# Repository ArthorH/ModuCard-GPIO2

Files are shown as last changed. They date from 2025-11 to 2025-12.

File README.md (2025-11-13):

# ModuCard Base Module STM32H563VBT6

This repository provides a template design for creating modules in the ModuCard system. Each module is designed to seamlessly interface with the [ModuCard backplane](https://github.com/KoNarRobotics/ModuCard-backplane), enabling a modular and expandable robotics platform.
obraz

## Used tools:
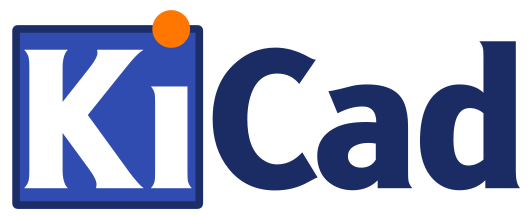
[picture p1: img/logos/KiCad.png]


## Features:

### Power section
- **Input voltage:** 12V from the backplane.  
- **Output voltage:** 3.3V @ 0.5A.

### ST-LINK
- Built-in **ST-LINK** connected to the backplane via USB interface.  
- Enables programming and debugging of the onboard MCU.

### CAN interface
- Two independent CAN buses: **CAN1** and **CAN2**.  
- Both connect with the backplane to facilitate communication between the onboard MCU and other modules in the system.

# How to Create a new module from this template
1. **Create a new repository**
2. **Copy files from this repository** to your new repository.  
3. **Rename the files:**
   - `base-module.kicad_pcb` → `<your-board-name>.kicad_pcb`
   - `base-module.kicad_sch` → `<your-board-name>.kicad_sch`
   - `base-module.kicad_pro` → `<your-board-name>.kicad_pro`
4. **Open the project** in KiCad.  
5. **Update page settings** in the schematic and PCB:
   - Change the **Title** to `ModuCard <your project name>`.  
   - Edit **Comment 2** to include your name in the `<author>` field.
6. Enjoy implementing your project!

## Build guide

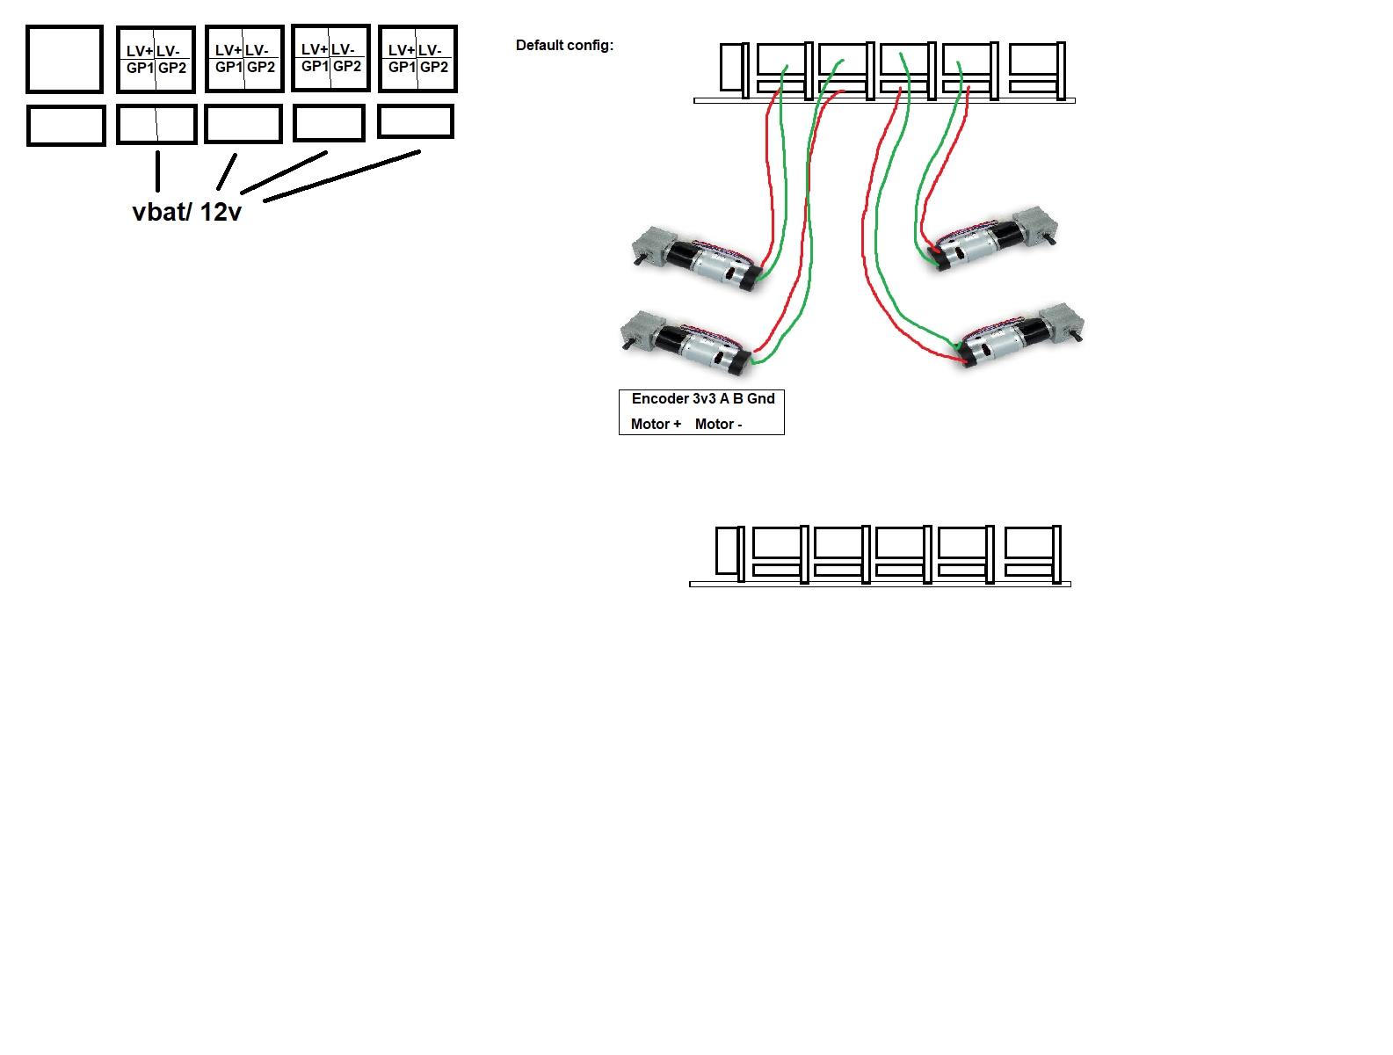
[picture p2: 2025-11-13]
doc/Usage.png

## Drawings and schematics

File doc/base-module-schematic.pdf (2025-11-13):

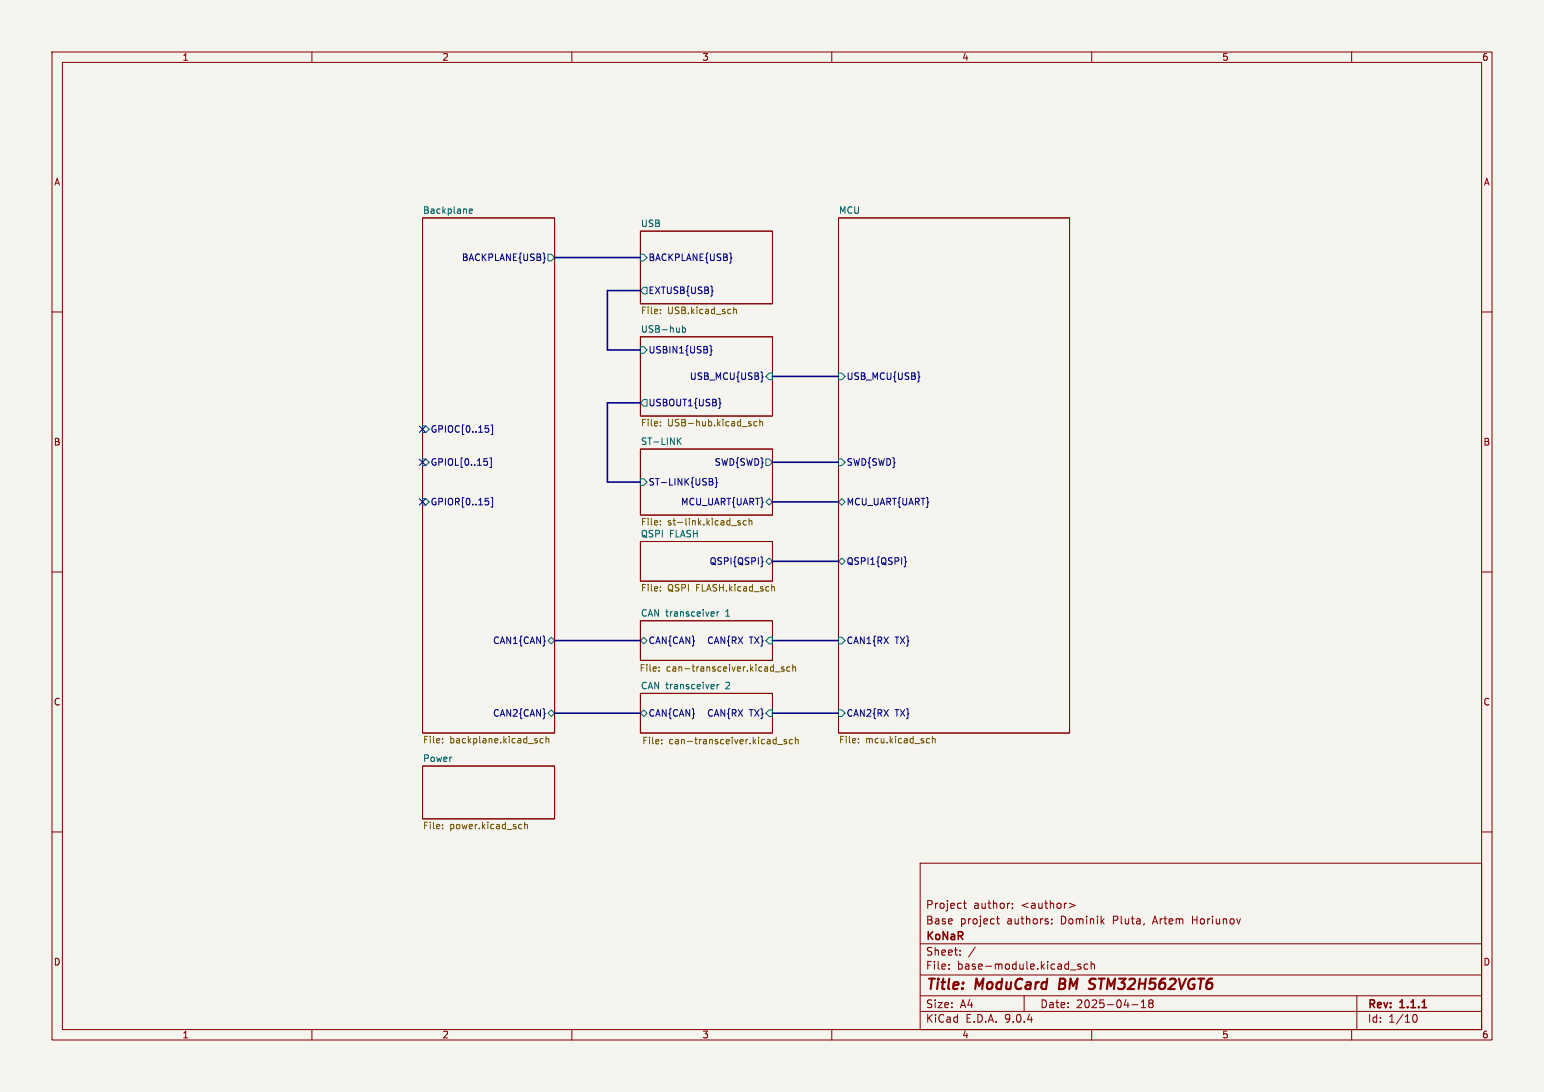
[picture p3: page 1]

Backplane File: backplane.kicad_sch
File: USB.kicad_sch ST-LINK{USB}
USB_MCU{USB} USB-hub File: USB-hub.kicad_sch

File: QSPI FLASH.kicad_sch USBIN1{USB}

File: st-link.kicad_sch QSPI{QSPI} QSPI FLASH

File: base-module.kicad_sch Sheet: / KoNaR

Id: 1/10 Title: ModuCard BM STM32H562VGT6

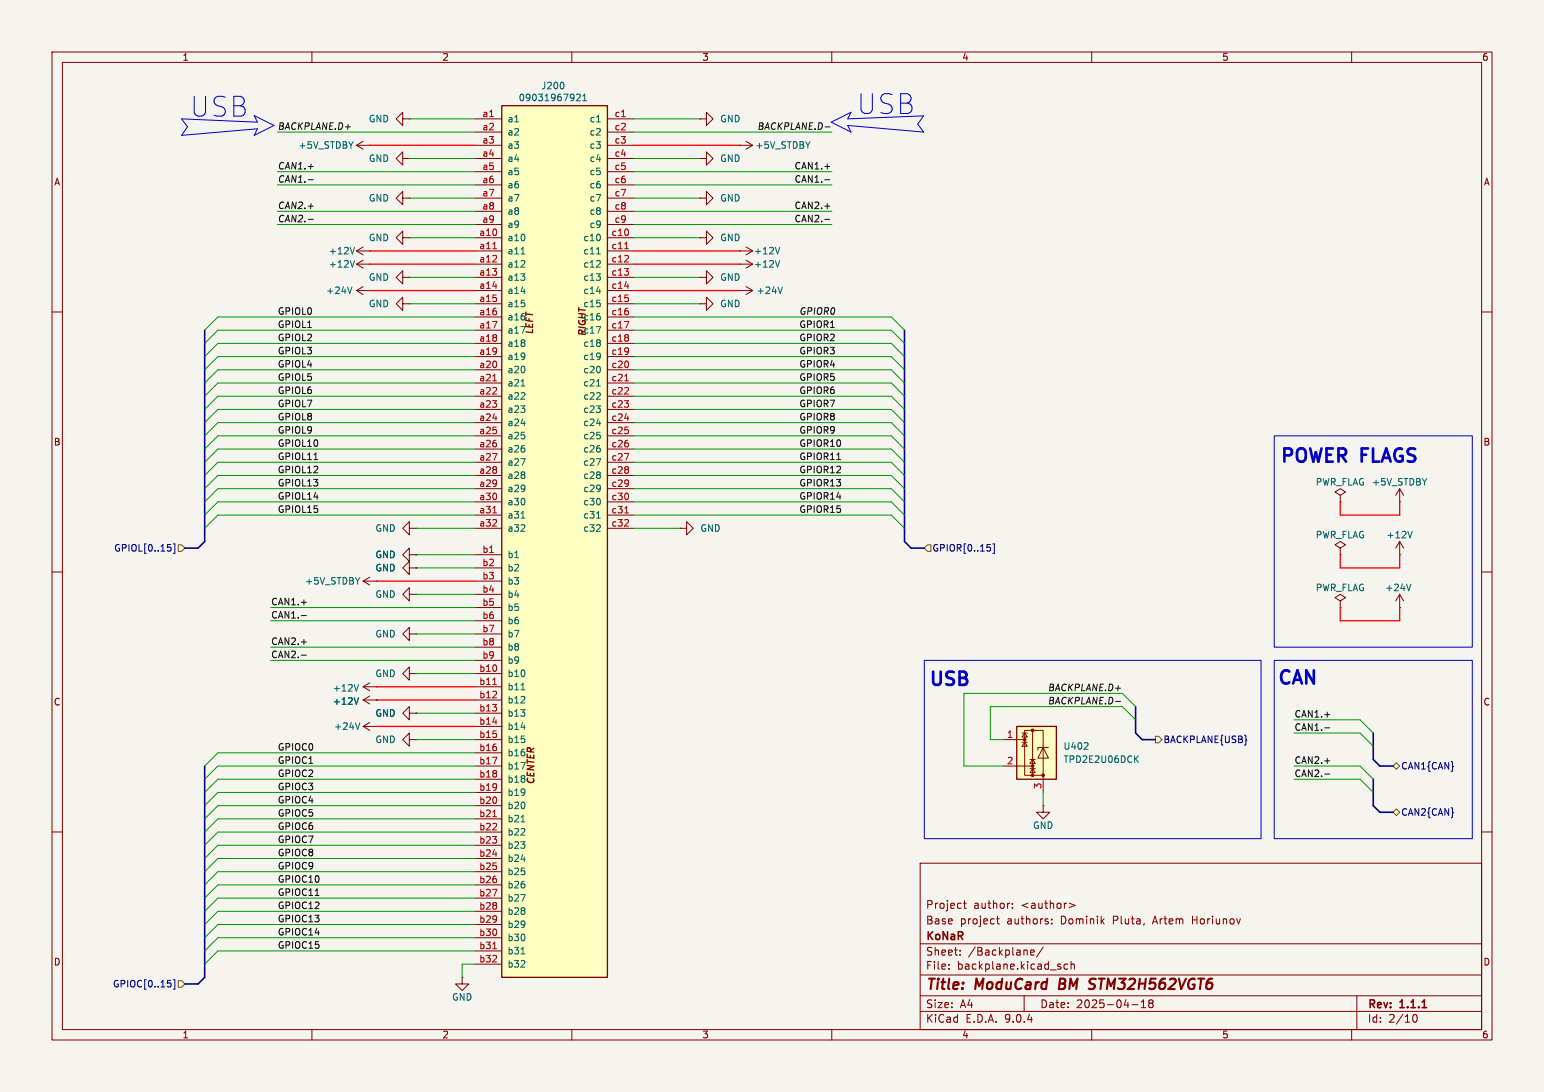
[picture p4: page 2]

File: backplane.kicad_sch Sheet: /Backplane/ KoNaR

Id: 2/10 Title: ModuCard BM STM32H562VGT6

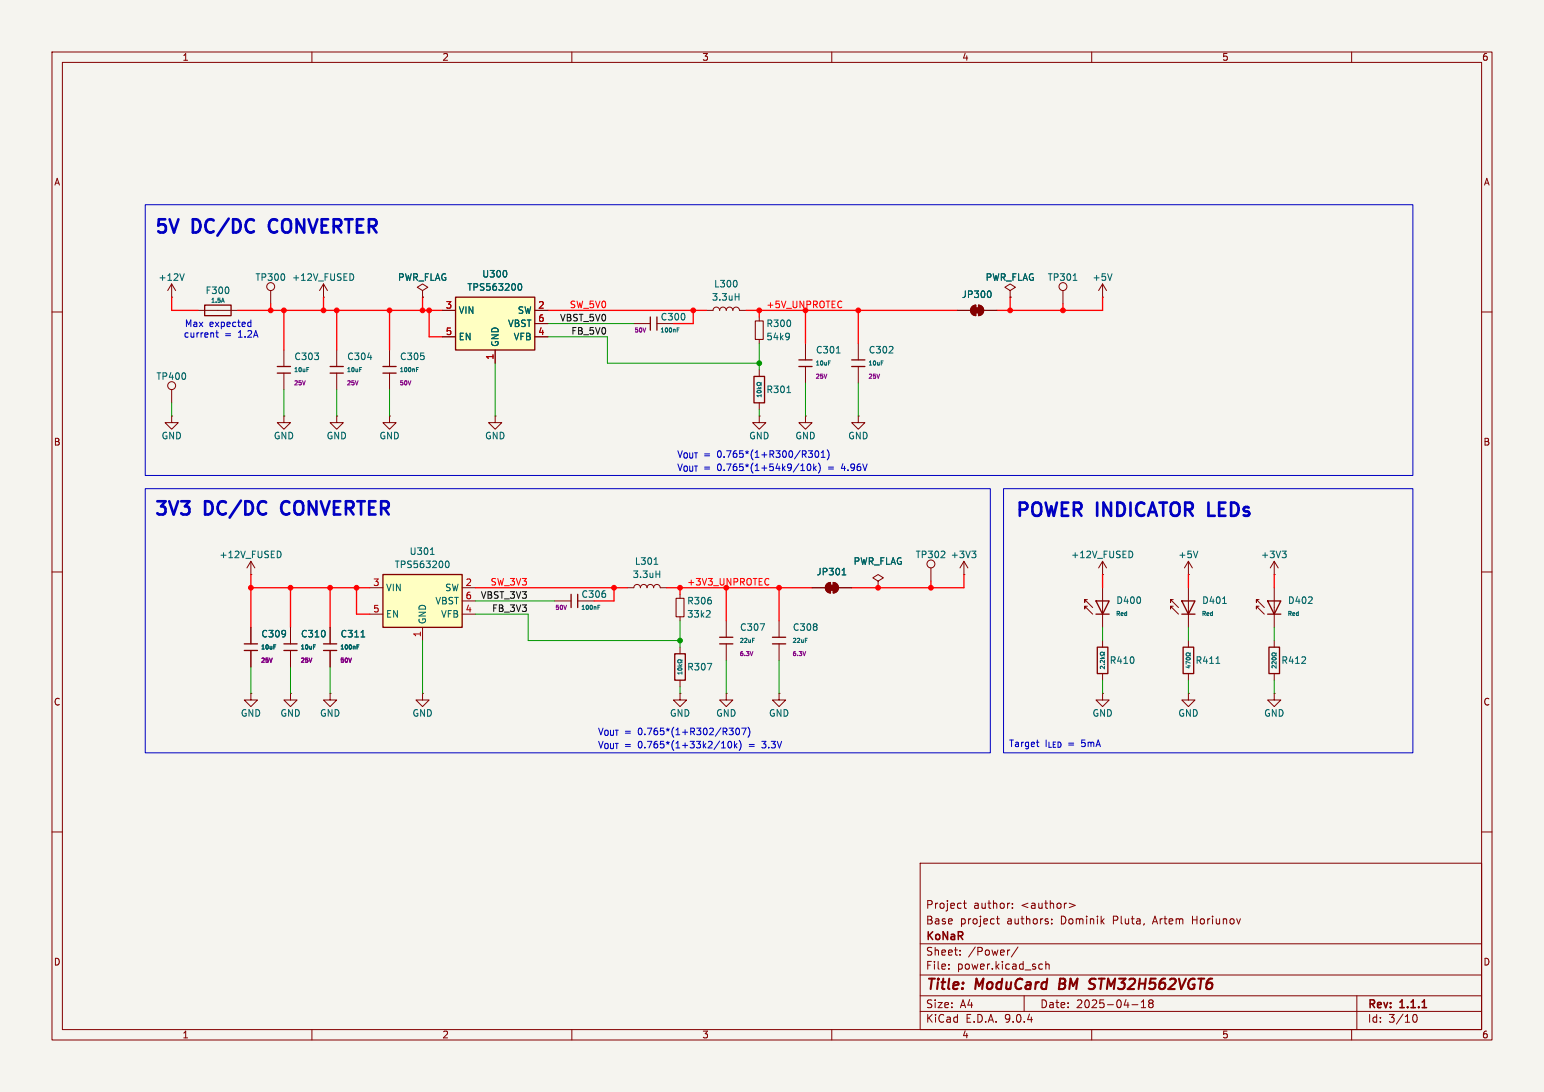
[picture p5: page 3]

1 SW 2 VBST 6 VFB 4 U300 TPS563200 GND GND

current = 1.2A 3V3 DC/DC CONVERTER

R412 þÿ220© +5VR411 þÿ470© R301 þÿ10k© GND

File: power.kicad_sch Sheet: /Power/ KoNaR

Id: 3/10 Title: ModuCard BM STM32H562VGT6

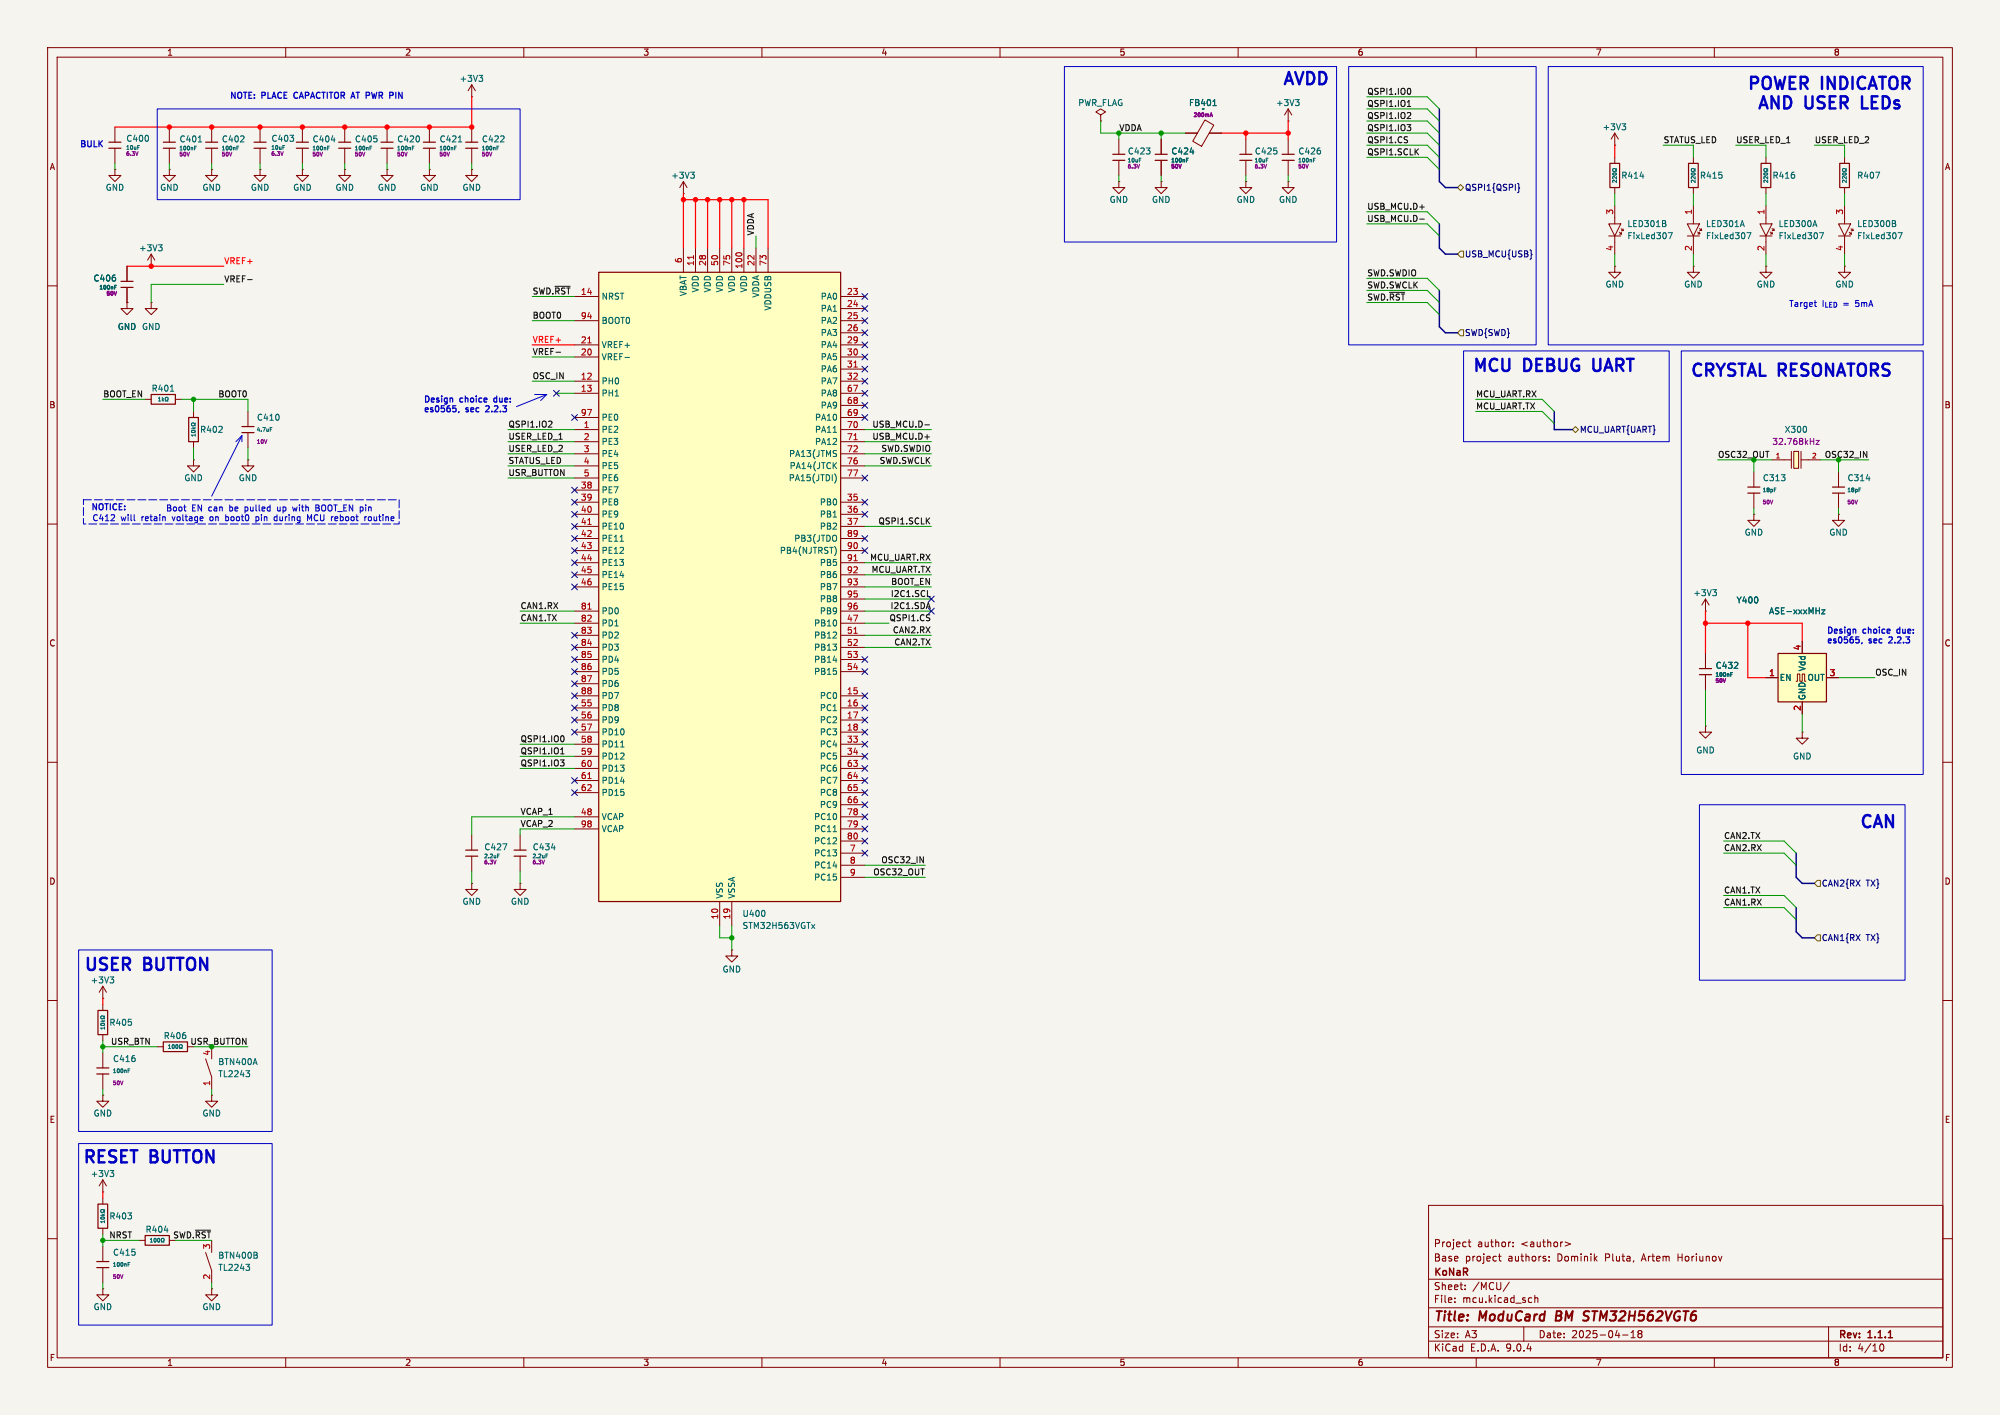
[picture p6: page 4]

6 VDD 11 VDD 28 VDD 50 VSS 10 VDD 75 VSSA 19 VDD 100 VDDA 22 VDDUSB 73 PA0 23 PA1 24 PA2 25 PA3 26 PA4 29 PA5 30 PA6 31 PA7 32 PA8 67 PA9 68 PA10 69 PA11 70 PA12 71 PA13(JTMS 72 PA14(JTCK 76 PA15(JTDI) 77 PB0 35 PB1 36 PB2 37 PB3(JTDO 89 PB4(NJTRST) 90 PB5 91 PB6 92 PB7 93 PB8 95 PB9 96 PB10 47 PB12 51 PB13 52 PB14 53 PB15 54 PC0 15 PC1 16 PC2 17 PC3 18 PC4 33 PC5 34 PC6 63 PC7 64 PC8 65 PC9 66 PC10 78 PC11 79 PC12 80 PC13 7 PC14 8 PC15 9 U400 STM32H563VGTx

File: mcu.kicad_sch Sheet: /MCU/ KoNaR

Id: 4/10 Title: ModuCard BM STM32H562VGT6

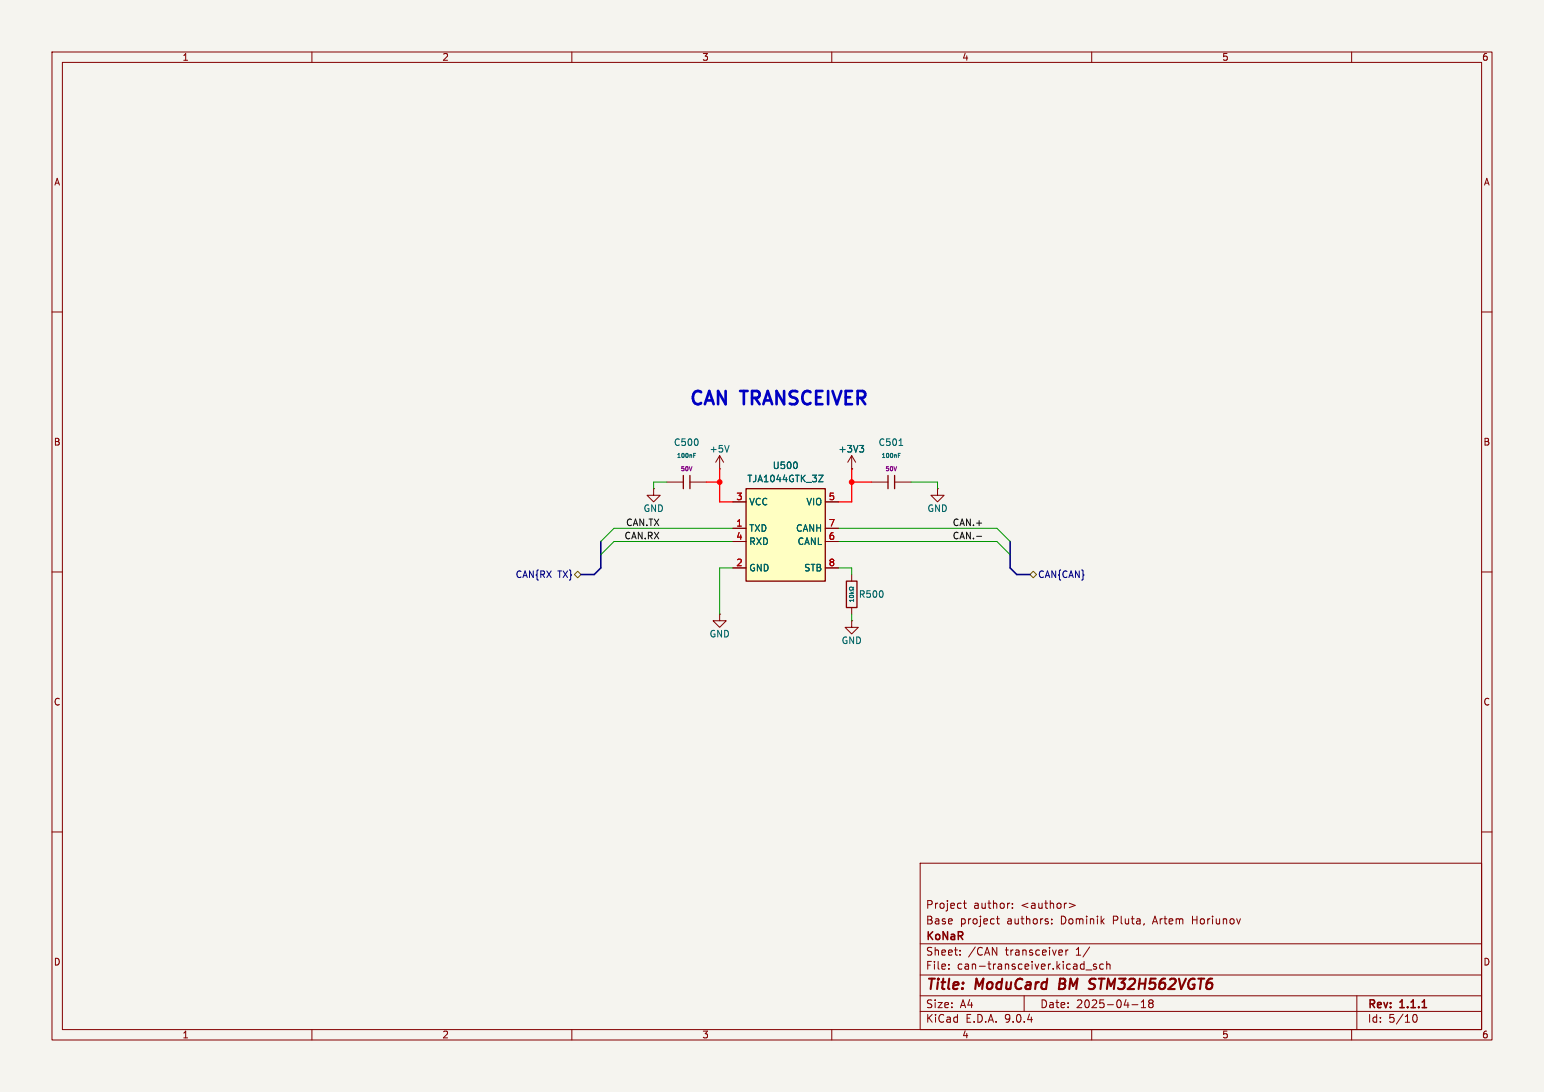
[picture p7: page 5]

Id: 5/10 Title: ModuCard BM STM32H562VGT6

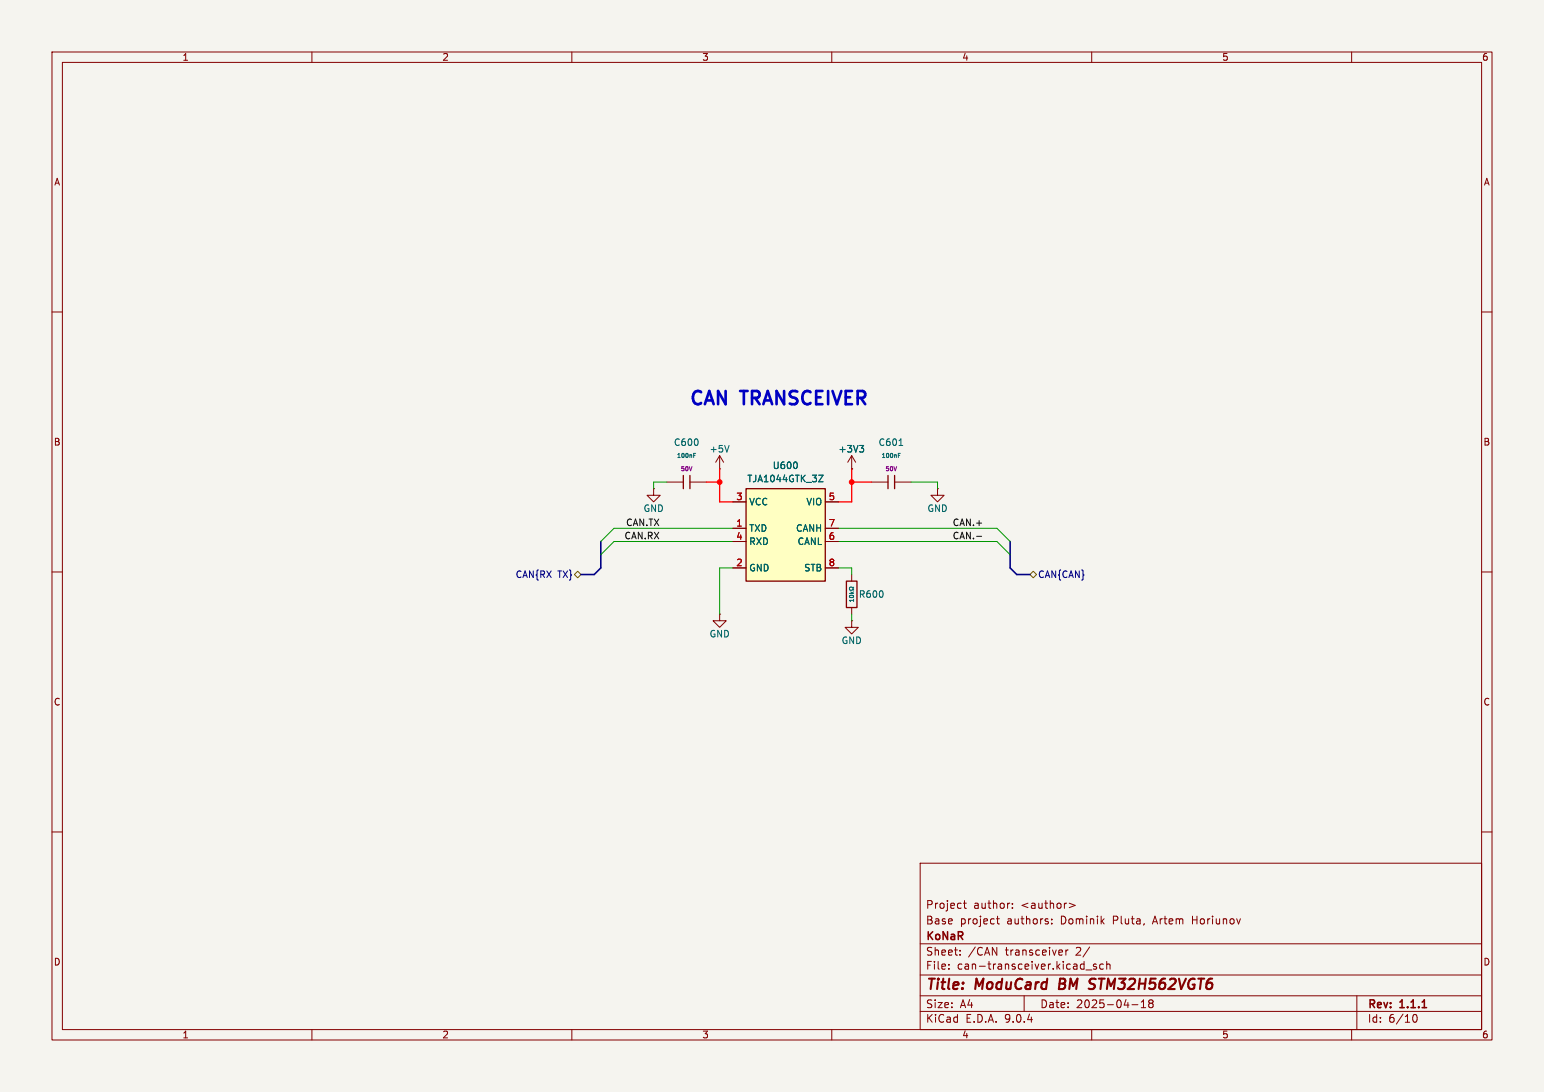
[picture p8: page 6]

Id: 6/10 Title: ModuCard BM STM32H562VGT6

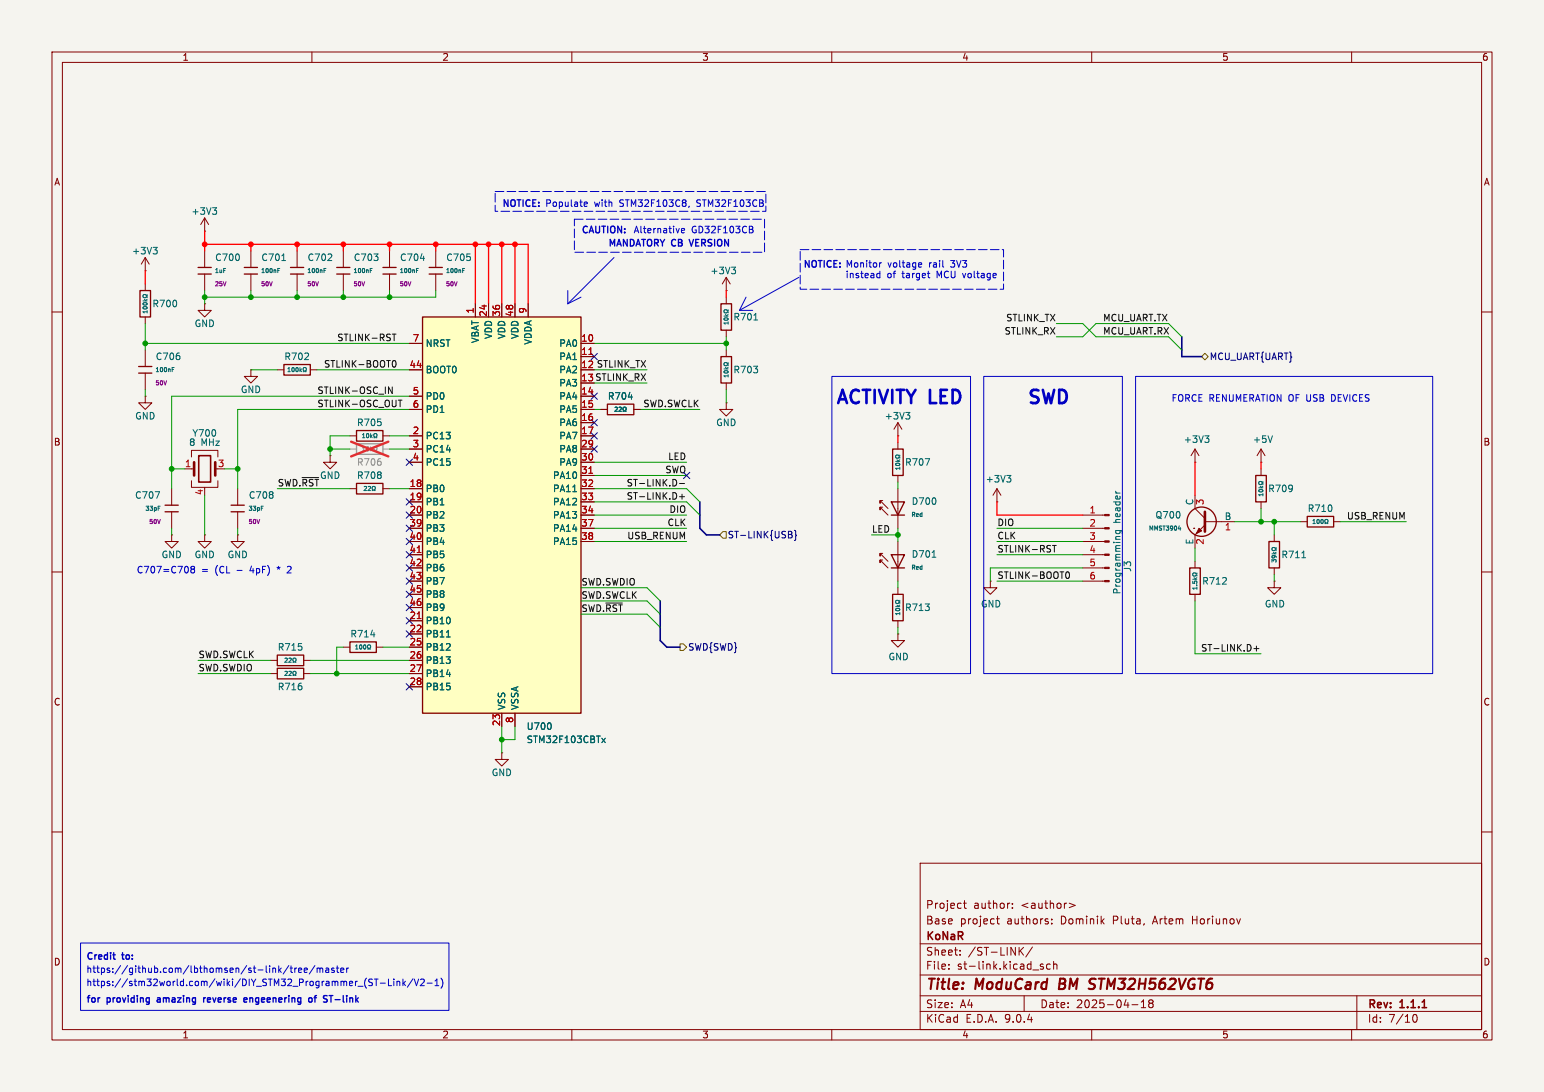
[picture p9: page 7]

instead of target MCU voltage

1 VDD 24 VDD 36 VSS 23 VDD 48 VSSA

ST-LINK.D+ ST-LINK.D- SWD.SWCLK

SWD.SWDIO
SWD.~{RST} SWD.SWCLK

File: st-link.kicad_sch Sheet: /ST-LINK/ KoNaR

https://stm32world.com/wiki/DIY_STM32_Programmer_(ST-Link/V2-1)
for providing amazing reverse engeenering of ST-link

Id: 7/10 Title: ModuCard BM STM32H562VGT6

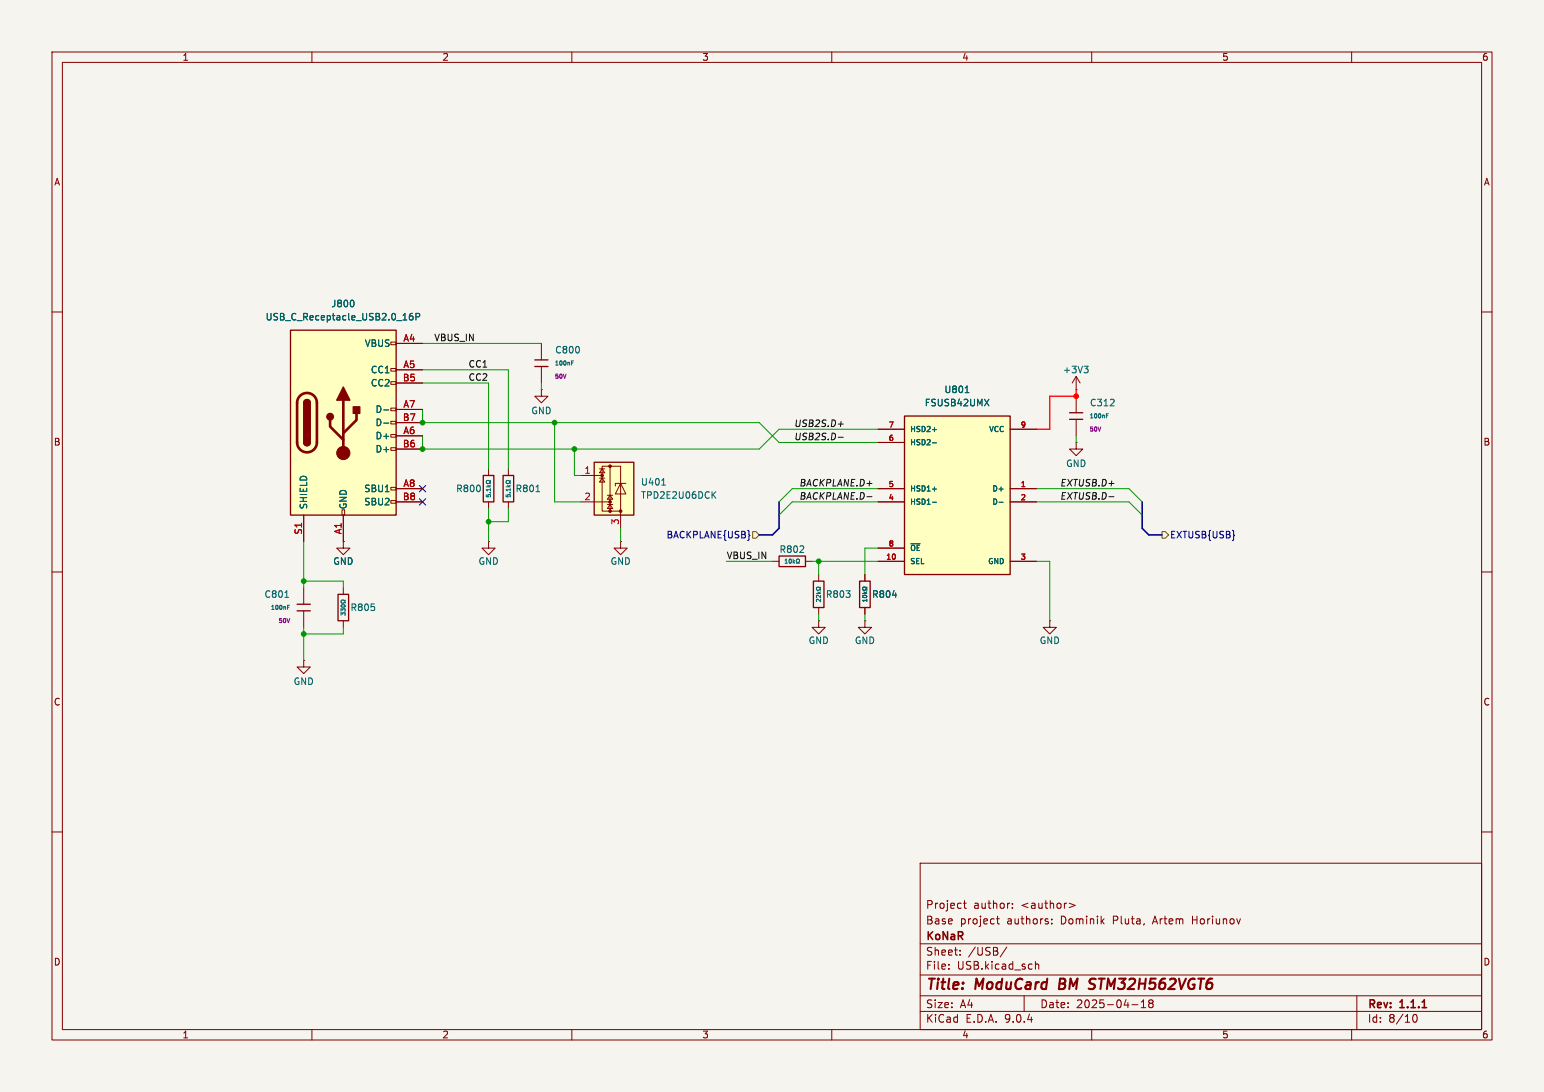
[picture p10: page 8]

File: USB.kicad_sch Sheet: /USB/ KoNaR

Id: 8/10 Title: ModuCard BM STM32H562VGT6

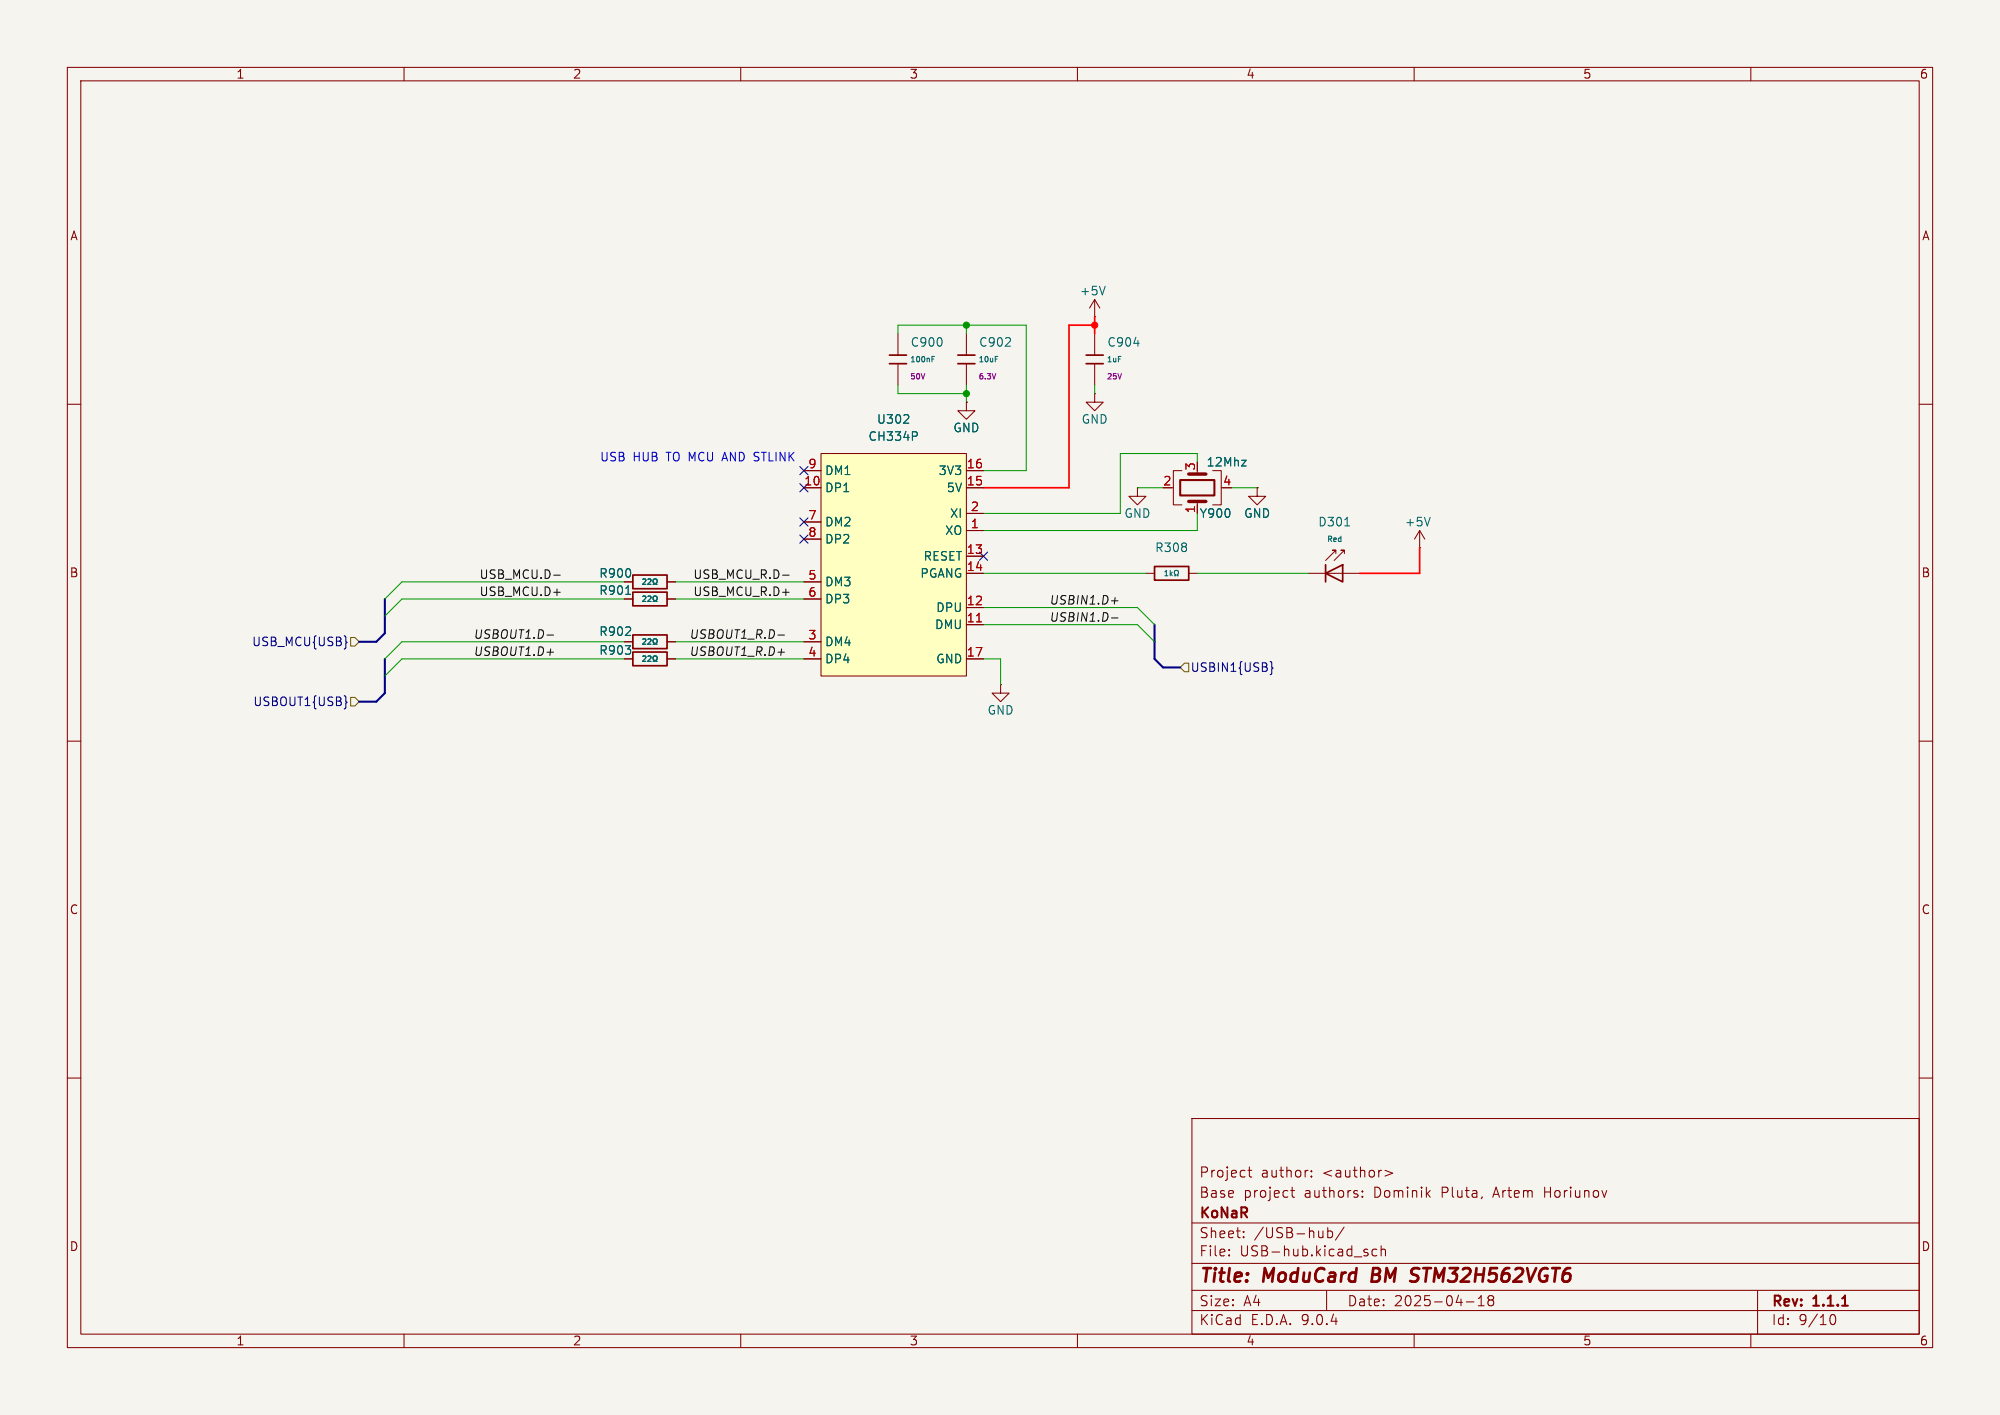
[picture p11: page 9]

File: USB-hub.kicad_sch Sheet: /USB-hub/ KoNaR

Id: 9/10 Title: ModuCard BM STM32H562VGT6

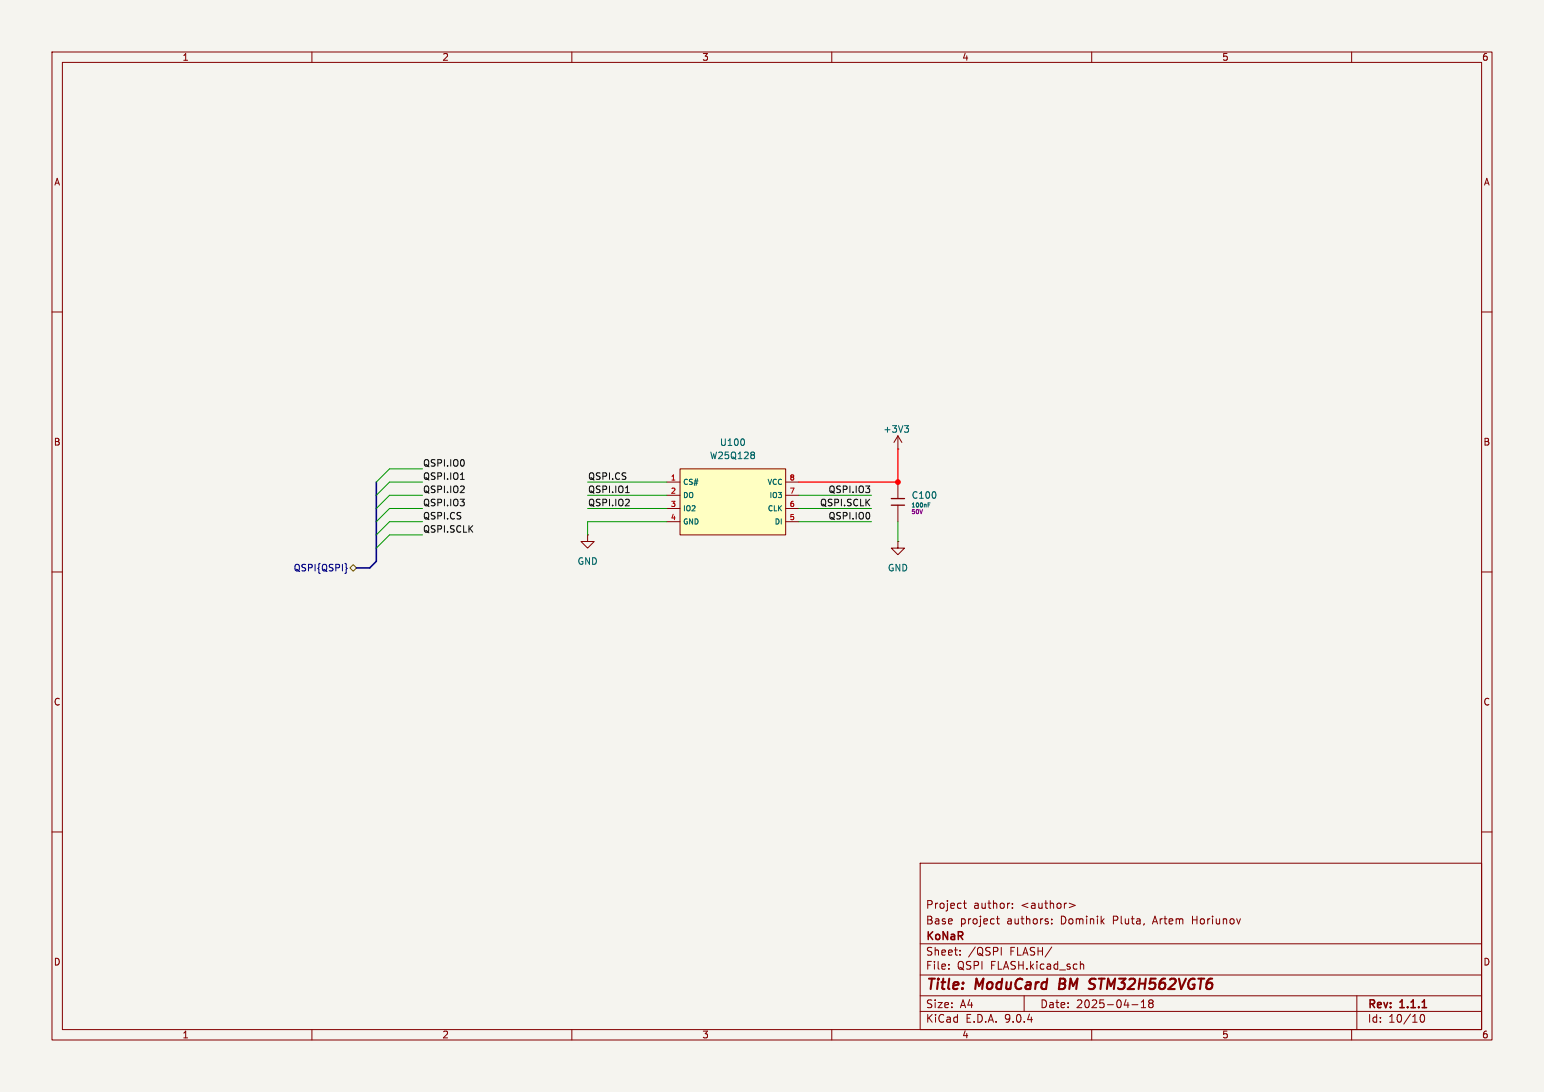
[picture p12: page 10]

Id: 10/10 Title: ModuCard BM STM32H562VGT6

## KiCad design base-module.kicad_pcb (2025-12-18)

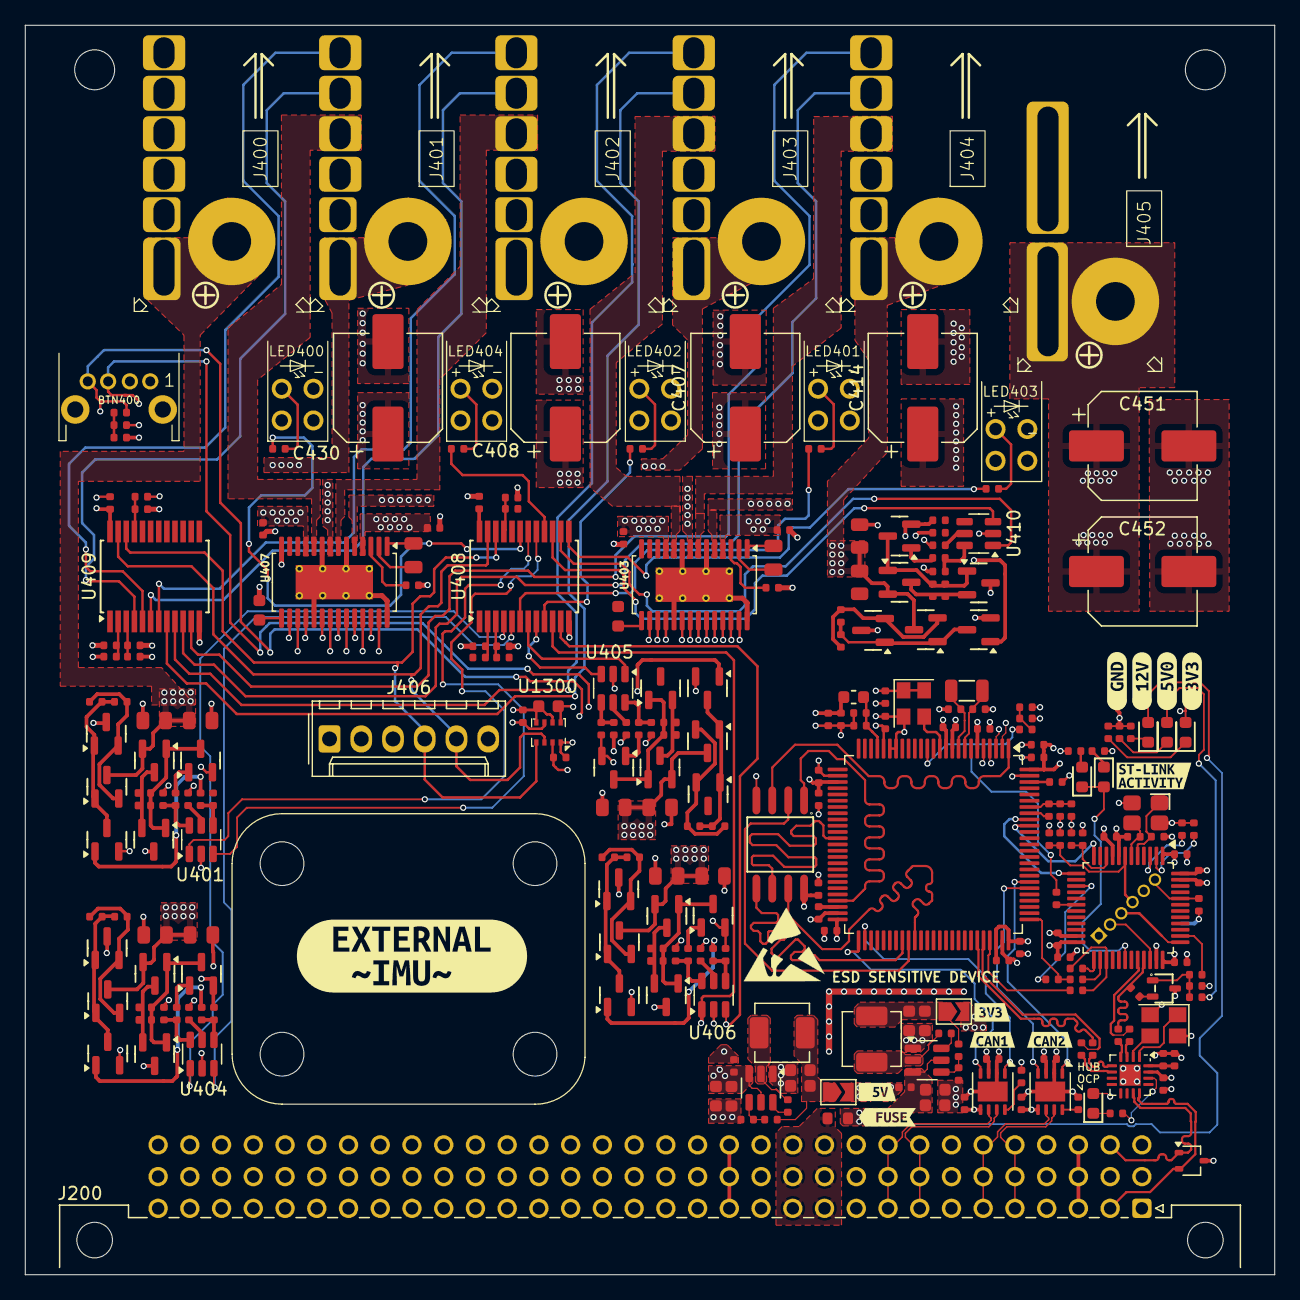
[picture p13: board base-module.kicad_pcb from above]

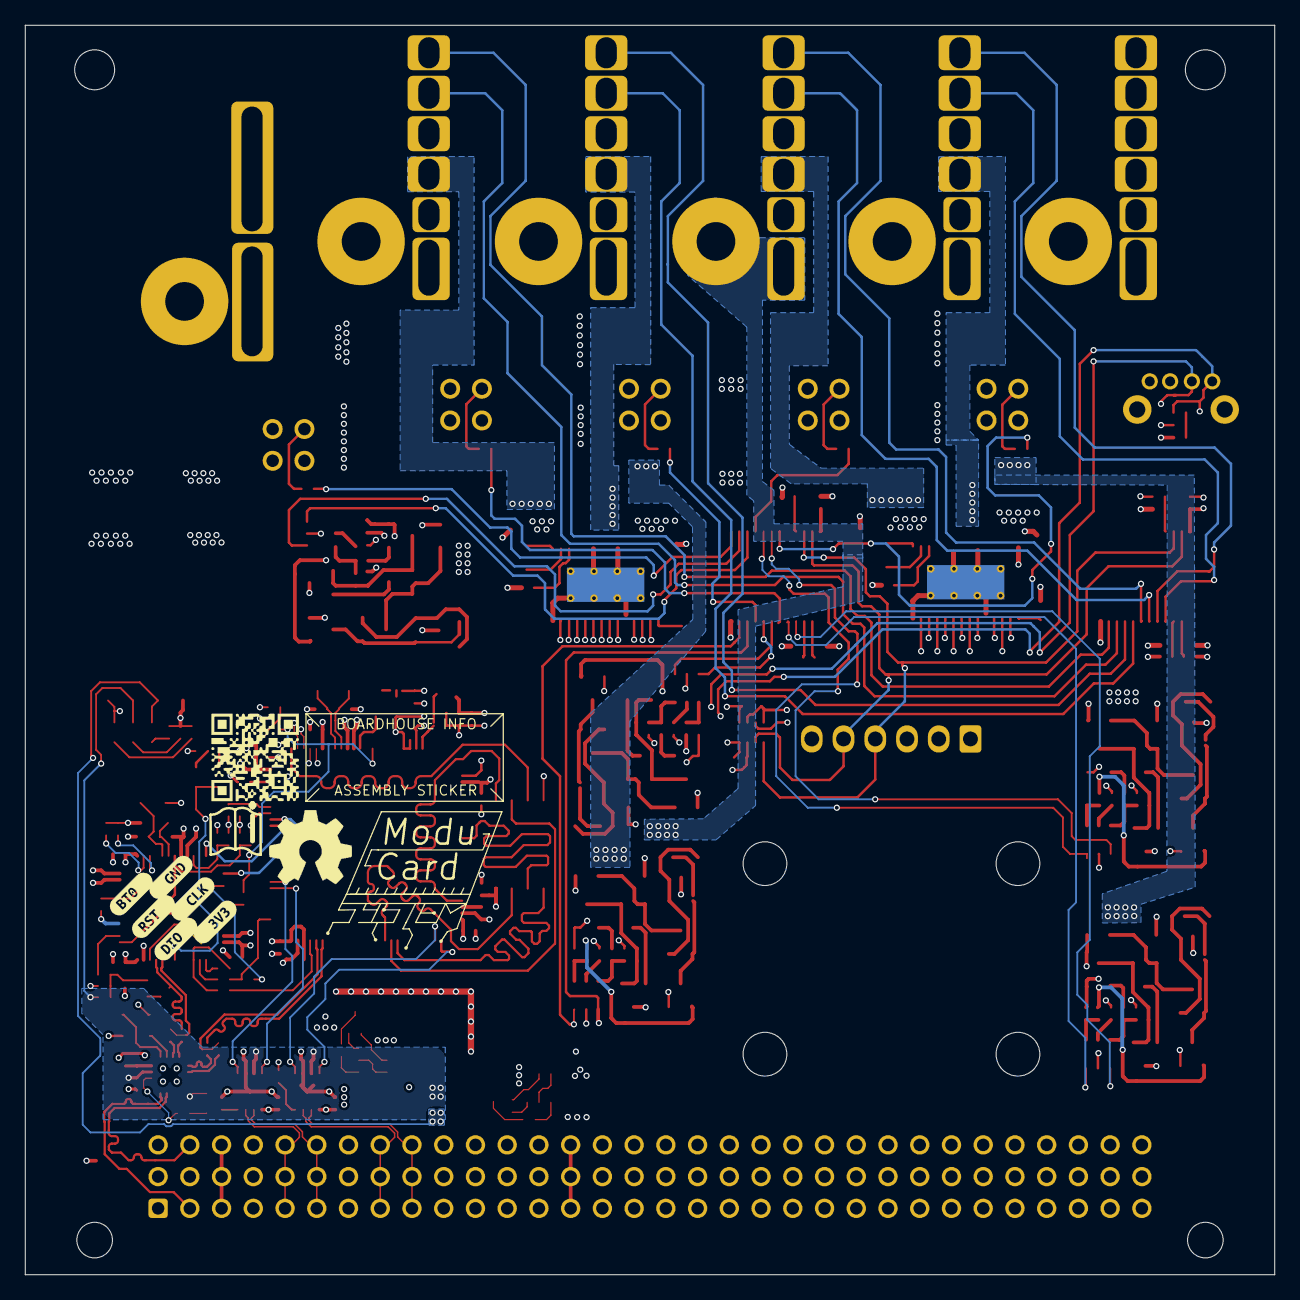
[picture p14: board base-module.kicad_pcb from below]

Board: 4 copper layers, 100.0 x 100.0 mm, 287 parts (7 on the bottom side), 183 nets.

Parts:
BTN400: TL2243
C100, C300, C305, C306, C311, C401, C402, C404, C405, C406, C412, C413, C415, C416, C420, C421, C422, C424, C426, C432, C433, C435, C436, C437, C438, C439, C440, C500, C501, C600, C601, C701, C702, C703, C704, C705, C706, C900, C1301, C1302: 100nF; C_0402
C301, C302, C303, C304, C309, C310, C1300: 10uF; C_0603
C307, C308: 22uF; C_0603
C313, C314: 18pF; C_0402
C400, C403, C423, C425, C902: 10uF; C_0402
C407, C408, C414, C430, C451, C452: 47uF; CP_Elec_8x10.5
C409, C411, C429, C431, C700, C904: 1uF; C_0402
C410: 4.7uF; C_0402
C417, C418: 100nF; C_0805
C419, C428: 47nF; C_0603
C427, C434: 2.2uF; C_0402
C441, C442, C443, C444, C445, C446, C447, C448, C449, C450: 10nF; C_0402
C707, C708: 33pF; C_0402
D301, D400, D401, D402, D700, D701: Red; D_0603
F300: 1.5A; R_0603
FB401: FB_0603
H400, H401, H402, H403: MountingHole; MountingHole_3.5mm
J3: Programming header; PinHeader_1x06_P1.27mm_Vertical
J200: 09031967921; DIN41612_R_3x32_Female_Horizontal_THT
J400, J401, J402, J403, J404: Conn_01x06_Socket; Molex-UP-righter
J405: XT60; XT60-RightAngle-Adapter
J406: Adafruit garbage connector; Molex_KK-254_AE-6410-06A_1x06_P2.54mm_Vertical
JP300, JP301: SolderJumper_2_Bridged; SolderJumper-2_P1.3mm_Open_TrianglePad1.0x1.5mm
L300, L301: 3.3uH; L_Changjiang_FXL0420
LED400, LED401, LED402, LED403, LED404: FixLed307
Q400, Q401, Q404, Q405, Q408, Q430, Q431, Q432, Q433, Q434: AO3400A; Q_SOT-23
Q402, Q403, Q406, Q407, Q410, Q411, Q414, Q415, Q418, Q419, Q420, Q421, Q422, Q423, Q424, Q425, Q426, Q427, Q428, Q429: AO3401A; Q_SOT-23
Q700: MMST3904; Q_SOT-323
R300: 54k9; R_0402
R301, R307, R402, R403, R405, R409, R413, R419, R420, R426, R427, R433, R434, R440, R441, R444, R445, R446, R447, R448, R449, R450, R451, R452, R453, R454, R455, R456, R457, R458, R459, R460, R461, R462, R463, R464, R465, R500, R600, R701, R703, R705, R706, R707, R709, R713: 10kΩ; R_0402
R306: 33k2; R_0402
R308, R401, R407, R408, R417, R418, R424, R425, R431, R432, R438, R439: 1kΩ; R_0402
R400, R412, R416, R423, R430, R437: 220Ω; R_0402
R404, R406, R710, R714: 100Ω; R_0402
R410: 2.2kΩ; R_0402
R411: 470Ω; R_0402
R414, R415, R421, R422, R428, R429, R435, R436, R442, R443: 0Ω; R_0805
R700, R702: 100kΩ; R_0402
R704, R708, R715, R716, R900, R901, R902, R903: 22Ω; R_0402
R711: 39kΩ; R_0402
R712: 1.5kΩ; R_0402
TP300, TP301, TP302, TP400: TestPoint; TestPoint_Pad_D1.0mm
U100: W25Q128; SOIC-8_L5.3-W5.3-P1.27-LS8.0-BL
U300, U301: TPS563200; SOT-23-6
U302: CH334P; QFN-16-1EP_3x3mm_P0.5mm_EP1.7x1.7mm
U400: STM32H563VGTx; LQFP-100_14x14mm_P0.5mm
U401, U404, U405, U406, U410: SN74LVC1G19DBVR; SOT-23-6
U402: TPD2E2U06DCK; SOT-323_SC-70
U403, U407: DRV8844PWPR; HTSSOP-28-1EP_4.4x9.7mm_P0.65mm_EP2.75x6.2mm_ThermalVias
U408, U409: TCA9535DBR; SSOP-24_5.3x8.2mm_P0.65mm
U500, U600: TJA1044GTK_3Z; HVSON-8-1EP_3x3mm_P0.65mm_EP1.6x2.4mm
U700: STM32F103CBTx; LQFP-48_7x7mm_P0.5mm
U1300: BMP280; Bosch_LGA-8_2x2.5mm_P0.65mm_ClockwisePinNumbering
X300: Q13FC1350000400; FC-135R_L3.2-W1.5
Y400: ASE-xxxMHz; Oscillator_SMD_Abracon_ASE-4Pin_3.2x2.5mm
Y700: 8 MHz; CRYSTAL-SMD_4P-L3.2-W2.5-BL
Y900: 12Mhz; Crystal_SMD_3225-4Pin_3.2x2.5mm
kibuzzard-67B20BD5: G***; kibuzzard-67B20BD5
kibuzzard-67B63E8D: G***; kibuzzard-67B63E8D
kibuzzard-67B643AC: G***; kibuzzard-67B643AC
kibuzzard-67B643DE: G***; kibuzzard-67B643DE
kibuzzard-67B643EE: G***; kibuzzard-67B643EE
kibuzzard-67B6249A: G***; kibuzzard-67B6249A
kibuzzard-67B6438D: G***; kibuzzard-67B6438D
kibuzzard-67B37005: G***; kibuzzard-67B37005
kibuzzard-67B37418: G***; kibuzzard-67B37418
kibuzzard-67B37472: G***; kibuzzard-67B37472
kibuzzard-67B62451: G***; kibuzzard-67B62451
kibuzzard-67E7D86B: G***; kibuzzard-67E7D86B
kibuzzard-68DC416C: G***; kibuzzard-68DC416C
kibuzzard-68DC4137: G***; kibuzzard-68DC4137
kibuzzard-68DC4152: G***; kibuzzard-68DC4152
kibuzzard-68DC4179: G***; kibuzzard-68DC4179
kibuzzard-6807DF1D: G***; kibuzzard-6807DF1D

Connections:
+3V3: C100.1, C400.1, C401.1, C402.1, C403.1, C404.1, C405.1, C406.1, C420.1, C421.1, C422.1, C425.1, C426.1, C432.1, C433.1, C435.1, C436.1, C437.1, C438.1, C501.1, C601.1, C700.1, C701.1, C702.1, C703.1, C704.1, C705.1, C1300.1, C1301.1, C1302.1, D402.2, FB401.2, J3.1, J406.2, JP301.2 (B), Q700.3 (C), R403.1, R405.1, R700.1, R701.1, R707.1, TP302.1, U100.8 (VCC), U400.6 (VBAT), U400.11 (VDD), U400.21 (VREF+), U400.28 (VDD), U400.50 (VDD), U400.73 (VDDUSB), U400.75 (VDD), U400.100 (VDD), U401.5 (VCC), U404.5 (VCC), U405.5 (VCC), U406.5 (VCC), U410.5 (VCC), U500.5 (VIO), U600.5 (VIO), U700.1 (VBAT), U700.9 (VDDA), U700.24 (VDD), U700.36 (VDD), U700.48 (VDD), U1300.2 (CSB), U1300.6 (VDDIO), U1300.8 (VDD), Y400.1 (EN), Y400.4 (Vdd)
+5V: C439.1, C440.1, C500.2, C600.2, C904.1, D301.2, D401.2, J406.1, JP300.2 (B), Q402.3 (D), Q406.3 (D), Q410.3 (D), Q414.3 (D), Q418.3 (D), R414.1, R421.1, R428.1, R435.1, R442.1, R444.1, R445.1, R446.1, R450.1, R452.1, R456.1, R709.1, TP301.1, U302.15 (5V), U408.24 (VCC), U409.24 (VCC), U500.3 (VCC), U600.3 (VCC)
+5V_STDBY: J200.a3, J200.b3, J200.c3
+12V: F300.1, J200.a11, J200.a12, J200.b11, J200.b12, J200.c11, J200.c12, Q403.3 (D), Q407.3 (D), Q411.3 (D), Q415.3 (D), Q419.3 (D), R415.1, R422.1, R429.1, R436.1, R443.1
+12V_FUSED: C303.1, C304.1, C305.2, C309.1, C310.1, C311.2, D400.2, F300.2, TP300.1, U300.3 (VIN), U300.5 (EN), U301.3 (VIN), U301.5 (EN)
+24V: J200.a14, J200.b14, J200.c14
/Backplane/BACKPLANE.D+: J200.a2, U302.12 (DPU), U402.2
/Backplane/BACKPLANE.D-: J200.c2, U302.11 (DMU), U402.1
/Backplane/CAN1.+: J200.a5, J200.b5, J200.c5, U500.7 (CANH)
/Backplane/CAN1.-: J200.a6, J200.b6, J200.c6, U500.6 (CANL)
/Backplane/CAN2.+: J200.a8, J200.b8, J200.c8, U600.7 (CANH)
/Backplane/CAN2.-: J200.a9, J200.b9, J200.c9, U600.6 (CANL)
/Barometer/BAROMETR_I2C.SCL: J406.4, U408.22 (SCL), U409.22 (SCL), U1300.4 (SCK)
/Barometer/BAROMETR_I2C.SDA: J406.5, U408.23 (SDA), U409.23 (SDA), U1300.3 (SDI)
/CAN transceiver 1/CAN.RX: U400.81 (PD0), U500.4 (RXD)
/CAN transceiver 1/CAN.TX: U400.82 (PD1), U500.1 (TXD)
/CAN transceiver 2/CAN.RX: U400.51 (PB12), U600.4 (RXD)
/CAN transceiver 2/CAN.TX: U400.52 (PB13), U600.1 (TXD)
/GPIO_Conn1/GPIO.Bridge+: J401.3, U407.8 (OUT3)
/GPIO_Conn1/GPIO.Bridge-: J401.4, U407.10 (OUT4)
/GPIO_Conn1/GPIO.EN: U404.3 (~E), U408.5 (P01)
/GPIO_Conn1/GPIO.GPIO1: J401.6, U409.5 (P01)
/GPIO_Conn1/GPIO.GPIO2: J401.5, U409.4 (P00)
/GPIO_Conn1/GPIO.LED: R416.1, U408.6 (P02)
/GPIO_Conn1/GPIO.LV+: J401.1, Q421.3 (D), Q426.2 (S), R421.2, R422.2
/GPIO_Conn1/GPIO.SEL: U404.1 (A), U408.4 (P00)
/GPIO_Conn2/GPIO.Bridge+: J402.3, U407.5 (OUT1)
/GPIO_Conn2/GPIO.Bridge-: J402.4, U407.7 (OUT2)
/GPIO_Conn2/GPIO.EN: U405.3 (~E), U408.8 (P04)
/GPIO_Conn2/GPIO.GPIO1: J402.6, U409.7 (P03)
/GPIO_Conn2/GPIO.GPIO2: J402.5, U409.6 (P02)
/GPIO_Conn2/GPIO.LED: R423.1, U408.9 (P05)
/GPIO_Conn2/GPIO.LV+: J402.1, Q422.3 (D), Q427.2 (S), R428.2, R429.2
/GPIO_Conn2/GPIO.SEL: U405.1 (A), U408.7 (P03)
/GPIO_Conn3/GPIO.Bridge+: J403.3, U403.8 (OUT3)
/GPIO_Conn3/GPIO.Bridge-: J403.4, U403.10 (OUT4)
/GPIO_Conn3/GPIO.EN: U406.3 (~E), U408.11 (P07)
/GPIO_Conn3/GPIO.GPIO1: J403.6, U409.9 (P05)
/GPIO_Conn3/GPIO.GPIO2: J403.5, U409.8 (P04)
/GPIO_Conn3/GPIO.LED: R430.1, U408.13 (P10)
/GPIO_Conn3/GPIO.LV+: J403.1, Q423.3 (D), Q428.2 (S), R435.2, R436.2
/GPIO_Conn3/GPIO.SEL: U406.1 (A), U408.10 (P06)
/GPIO_Conn4/GPIO.Bridge+: J404.3, U403.5 (OUT1)
/GPIO_Conn4/GPIO.Bridge-: J404.4, U403.7 (OUT2)
/GPIO_Conn4/GPIO.EN: U408.15 (P12), U410.3 (~E)
/GPIO_Conn4/GPIO.GPIO1: J404.6, U409.11 (P07)
/GPIO_Conn4/GPIO.GPIO2: J404.5, U409.10 (P06)
/GPIO_Conn4/GPIO.LED: R437.1, U408.16 (P13)
/GPIO_Conn4/GPIO.LV+: J404.1, Q424.3 (D), Q429.2 (S), R442.2, R443.2
/GPIO_Conn4/GPIO.SEL: U408.14 (P11), U410.1 (A)
/GPIO_Conn5/GPIO.EN: U401.3 (~E), U408.18 (P15)
/GPIO_Conn5/GPIO.LED: R400.1, U408.19 (P16)
/GPIO_Conn5/GPIO.LV+: J400.1, Q420.3 (D), Q425.2 (S), R414.2, R415.2
/GPIO_Conn5/GPIO.SEL: U401.1 (A), U408.17 (P14)
/Hbridge1-2/VM: C407.1, C408.1, C409.1, C411.1, C414.1, C429.1, C430.1, C431.1, C451.1, C452.1, J405.1, U403.4 (VM), U403.11 (VM), U407.4 (VM), U407.11 (VM)
/MCU/BOOT0: C410.1, R401.2, R402.1, U400.94 (BOOT0)
/MCU/BOOT_EN: R401.1, U400.93 (PB7)
/MCU/MCU_UART.RX: U400.91 (PB5), U700.12 (PA2)
/MCU/MCU_UART.TX: U400.92 (PB6), U700.13 (PA3)
/MCU/NRST: C415.1, R403.2, R404.1
/MCU/OSC32_IN: C314.1, U400.8 (PC14), X300.2
/MCU/OSC32_OUT: C313.1, U400.9 (PC15), X300.1
/MCU/OSC_IN: U400.12 (PH0), Y400.3 (OUT)
/MCU/QSPI1.CS: U100.1 (CS#), U400.47 (PB10)
/MCU/QSPI1.IO0: U100.5 (DI), U400.58 (PD11)
/MCU/QSPI1.IO1: U100.2 (DO), U400.59 (PD12)
/MCU/QSPI1.IO2: U100.3 (IO2), U400.1 (PE2)
/MCU/QSPI1.IO3: U100.7 (IO3), U400.60 (PD13)
/MCU/QSPI1.SCLK: U100.6 (CLK), U400.37 (PB2)
/MCU/SWD.SWCLK: R704.2, R715.1, U400.76 (PA14(JTCK)
/MCU/SWD.SWDIO: R716.1, U400.72 (PA13(JTMS)
/MCU/SWD.~RST: BTN400.3, R404.2, R708.1, U400.14 (NRST)
/MCU/USB_MCU.D+: R901.1, U400.71 (PA12)
/MCU/USB_MCU.D-: R900.1, U400.70 (PA11)
/MCU/USR_BTN: C416.1, R405.2, R406.1
/MCU/USR_BUTTON: BTN400.4, R406.2, U400.5 (PE6)
/MCU/VCAP_1: C427.1, U400.48 (VCAP)
/MCU/VCAP_2: C434.1, U400.98 (VCAP)
/MCU/VDDA: C423.1, C424.1, FB401.1, U400.22 (VDDA)
/Power/+3V3_UNPROTEC: C307.1, C308.1, JP301.1 (A), L301.2, R306.1
/Power/+5V_UNPROTEC: C301.1, C302.1, JP300.1 (A), L300.2, R300.1
/Power/FB_3V3: R306.2, R307.1, U301.4 (VFB)
/Power/FB_5V0: R300.2, R301.1, U300.4 (VFB)
/Power/SW_3V3: C306.2, L301.1, U301.2 (SW)
/Power/SW_5V0: C300.2, L300.1, U300.2 (SW)
/Power/VBST_3V3: C306.1, U301.6 (VBST)
/Power/VBST_5V0: C300.1, U300.6 (VBST)
/ST-LINK/CLK: J3.3, U700.37 (PA14)
/ST-LINK/DIO: J3.2, U700.34 (PA13)
/ST-LINK/LED: D700.1, D701.2, U700.30 (PA9)
/ST-LINK/ST-LINK.D+: R712.2, R903.1, U700.33 (PA12)
/ST-LINK/ST-LINK.D-: R902.1, U700.32 (PA11)
/ST-LINK/STLINK-BOOT0: J3.6, R702.2, U700.44 (BOOT0)
/ST-LINK/STLINK-OSC_IN: C707.1, U700.5 (PD0), Y700.1
/ST-LINK/STLINK-OSC_OUT: C708.1, U700.6 (PD1), Y700.3
/ST-LINK/STLINK-RST: C706.1, J3.4, R700.2, U700.7 (NRST)
/ST-LINK/USB_RENUM: R710.2, U700.38 (PA15)
/USB-hub/USBOUT1_R.D+: R903.2, U302.4 (DP4)
/USB-hub/USBOUT1_R.D-: R902.2, U302.3 (DM4)
/USB-hub/USB_MCU_R.D+: R901.2, U302.6 (DP3)
/USB-hub/USB_MCU_R.D-: R900.2, U302.5 (DM3)
GND: BTN400.1, BTN400.2, C100.2, C301.2, C302.2, C303.2, C304.2, C305.1, C307.2, C308.2, C309.2, C310.2, C311.1, C313.2, C314.2, C400.2, C401.2, C402.2, C403.2, C404.2, C405.2, C406.2, C407.2, C408.2, C409.2, C410.2, C411.2, C412.1, C413.1, C414.2, C415.2, C416.2, C419.2, C420.2, C421.2, C422.2, C423.2, C424.2, C425.2, C426.2, C427.2, C428.2, C429.2, C430.2, C431.2, C432.2, C433.2, C434.2, C435.2, C436.2, C437.2, C438.2, C439.2, C440.2, C451.2, C452.2, C500.1, C501.2, C600.1, C601.2, C700.2, C701.2, C702.2, C703.2, C704.2, C705.2, C706.2, C707.2, C708.2, C900.2, C902.2, C904.2, C1300.2, C1301.2, C1302.2, J3.5, J200.a1, J200.a4, J200.a7, J200.a10, J200.a13, J200.a15, J200.a32, J200.b1, J200.b2, J200.b4, J200.b7, J200.b10, J200.b13, J200.b15, J200.b32, J200.c1, J200.c4, J200.c7, J200.c10, J200.c13, J200.c15, J200.c32, J400.2, J401.2, J402.2, J403.2, J404.2, J405.2, J406.3, LED400.2, LED401.2, LED402.2, LED403.2, LED404.2, Q400.2 (S), Q401.2 (S), Q404.2 (S), Q405.2 (S), Q408.2 (S), Q430.2 (S), Q431.2 (S), Q432.2 (S), Q433.2 (S), Q434.2 (S), R301.2, R307.2, R402.2, R410.2, R411.2, R412.2, R413.2, R420.2, R427.2, R434.2, R441.2, R447.2, R448.2, R449.2, R451.2, R454.2, R455.2, R461.2, R462.2, R463.2, R464.2, R465.2, R500.2, R600.2, R702.1, R703.2, R705.1, R706.1, R711.2, R713.2, TP400.1, U100.4 (GND), U300.1 (GND), U301.1 (GND), U302.17 (GND), U400.10 (VSS), U400.19 (VSSA), U400.20 (VREF-), U400.27 (VSS), U400.49 (VSS), U400.74 (VSS), U400.99 (VSS), U401.2 (GND), U402.3, U403.6 (SRC12), U403.9 (SRC34), U403.14 (VNEG), U403.19 (LGND), U403.28 (VNEG), U403.29 (PAD), U404.2 (GND), U405.2 (GND), U406.2 (GND), U407.6 (SRC12), U407.9 (SRC34), U407.14 (VNEG), U407.19 (LGND), U407.28 (VNEG), U407.29 (PAD), U408.12 (GND), U409.12 (GND), U410.2 (GND), U500.2 (GND), U500.9 (EP), U600.2 (GND), U600.9 (EP), U700.8 (VSSA), U700.23 (VSS), U700.35 (VSS), U700.47 (VSS), U1300.1 (GND), U1300.5 (SDO), U1300.7 (GND), Y400.2 (GND), Y700.2, Y700.4, Y900.2, Y900.4
unnamed: D301.1, R308.2
unnamed: D400.1, R410.1
unnamed: D401.1, R411.1
unnamed: D402.1, R412.1
unnamed: D700.2, R707.2
unnamed: D701.1, R713.1
unnamed: LED400.1, R400.2
unnamed: LED401.1, R416.2
unnamed: LED402.1, R423.2
unnamed: LED403.1, R430.2
unnamed: LED404.1, R437.2
unnamed: C446.1, Q400.3 (D), Q403.1 (G), Q420.1 (G), R453.1
unnamed: Q400.1 (G), R408.2
unnamed: C447.1, Q401.3 (D), Q407.1 (G), Q421.1 (G), R457.1
unnamed: Q401.1 (G), R418.2
unnamed: C441.1, Q402.1 (G), Q425.1 (G), Q430.3 (D), R409.1
unnamed: C441.2, Q402.2 (S), Q425.3 (D), R409.2
unnamed: C446.2, Q403.2 (S), Q420.2 (S), R453.2
unnamed: C448.1, Q404.3 (D), Q411.1 (G), Q422.1 (G), R458.1
unnamed: Q404.1 (G), R425.2
unnamed: C449.1, Q405.3 (D), Q415.1 (G), Q423.1 (G), R459.1
unnamed: Q405.1 (G), R432.2
unnamed: C442.1, Q406.1 (G), Q426.1 (G), Q431.3 (D), R419.1
unnamed: C442.2, Q406.2 (S), Q426.3 (D), R419.2
unnamed: C447.2, Q407.2 (S), Q421.2 (S), R457.2
unnamed: C450.1, Q408.3 (D), Q419.1 (G), Q424.1 (G), R460.1
unnamed: Q408.1 (G), R439.2
unnamed: C443.1, Q410.1 (G), Q427.1 (G), Q432.3 (D), R426.1
unnamed: C443.2, Q410.2 (S), Q427.3 (D), R426.2
unnamed: C448.2, Q411.2 (S), Q422.2 (S), R458.2
unnamed: C444.1, Q414.1 (G), Q428.1 (G), Q433.3 (D), R433.1
unnamed: C444.2, Q414.2 (S), Q428.3 (D), R433.2
unnamed: C449.2, Q415.2 (S), Q423.2 (S), R459.2
unnamed: C445.1, Q418.1 (G), Q429.1 (G), Q434.3 (D), R440.1
unnamed: C445.2, Q418.2 (S), Q429.3 (D), R440.2
unnamed: C450.2, Q419.2 (S), Q424.2 (S), R460.2
unnamed: Q430.1 (G), R407.2
unnamed: Q431.1 (G), R417.2
unnamed: Q432.1 (G), R424.2
unnamed: Q433.1 (G), R431.2
unnamed: Q434.1 (G), R438.2
unnamed: Q700.1 (B), R709.2, R710.1, R711.1
unnamed: Q700.2 (E), R712.1
unnamed: C900.1, C902.1, U302.16 (3V3)
unnamed: R308.1, U302.14 (PGANG)
unnamed: U302.2 (XI), Y900.3
unnamed: U302.1 (XO), Y900.1
unnamed: R407.1, R413.1, U401.6 (Y0)
unnamed: R408.1, R461.1, U401.4 (Y1)
unnamed: C417.2, U403.1 (CP1)
unnamed: C417.1, U403.2 (CP2)
unnamed: C419.1, U403.15 (V3P3OUT)
unnamed: C413.2, U403.3 (VCP)
unnamed: R417.1, R420.1, U404.6 (Y0)
unnamed: R418.1, R462.1, U404.4 (Y1)
unnamed: R424.1, R427.1, U405.6 (Y0)
unnamed: R425.1, R463.1, U405.4 (Y1)
unnamed: R431.1, R434.1, U406.6 (Y0)
unnamed: R432.1, R464.1, U406.4 (Y1)
unnamed: C418.2, U407.1 (CP1)
unnamed: C418.1, U407.2 (CP2)
unnamed: C428.1, U407.15 (V3P3OUT)
unnamed: C412.2, U407.3 (VCP)
unnamed: R446.2, R449.1, U408.21 (A0)
unnamed: R445.2, R448.1, U408.2 (A1)
unnamed: R444.2, R447.1, U408.3 (A2)
unnamed: R454.1, R456.2, U409.21 (A0)
unnamed: R452.2, R455.1, U409.2 (A1)
unnamed: R450.2, R451.1, U409.3 (A2)
unnamed: R438.1, R441.1, U410.6 (Y0)
unnamed: R439.1, R465.1, U410.4 (Y1)
unnamed: R500.1, U500.8 (STB)
unnamed: R600.1, U600.8 (STB)
unnamed: R701.2, R703.1, U700.10 (PA0)
unnamed: R704.1, U700.15 (PA5)
unnamed: R708.2, U700.18 (PB0)
unnamed: R714.2, U700.25 (PB12)
unnamed: R715.2, U700.26 (PB13)
unnamed: R714.1, R716.2, U700.27 (PB14)
unnamed: R705.2, U700.2 (PC13)
unnamed: R706.2, U700.3 (PC14)
